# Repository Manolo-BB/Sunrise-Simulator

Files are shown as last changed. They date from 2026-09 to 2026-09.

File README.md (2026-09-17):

# Sunrise-Simulator
The aim of this project is to create a sunrise simulator to replace my mobile phone as an alarm clock. It works independently, without the need for an app. A second aim is to be cheaper than the alarm clocks currently available on the market, whilst still incorporating all the features I want.

## License

This project is licensed under the CC BY-NC-SA 4.0 License.

You may use, modify and distribute this project for non-commercial purposes.
Commercial use is not permitted.

See the [LICENSE](./LICENSE) file for details.

## Features

### General
- Run on main power and a backup battery
- Permanent time display + backlight when a button is pressed (The time is updated every minute via the RTC module. The local time is updated via Wi-Fi every 24 hours at 3:30am to take account of time changes)

### Alarm clock
- Set the alarm time
- Select the wake-up interval (default 30 mins)
- Choose an alarm tone (selection of 5 sounds)
- Alarm scheduling feature (weekdays/weekends)
- Ability to turn off the alarm before it ring
- Ability to set multiple alarms simultaneously

### lighting
- Switching on the light in bedside lamp mode
- Selecting easily the light 
- Selecting the brightness level

## Material
The idea is to reuse personal items rather than buying new ones; that is why some components may not be optimised. The whole project is designed to work with a 12V LED strip.

### Hardware

| Function | Component | Price |
| --- | --- | ---: |
| Microcontroller / Main Control | ESP32 DevKit V1 | €5.99 |
| Lighting | WS2812B LED Strip | Personal stock |
| Power Supply | 12 V – 1.5 A AC/DC Power Supply | Second-hand |
| Power Connector | DC Female PCB Connector | €0.32 |
| Voltage Regulation | MP1584EN Buck Converter | €1.15 |
| **Audio / Alarm** | MAX98357A Audio Amplifier | €1.72 |
| | 4 Ω – 3 W Speaker | Personal stock |
| | Micro SD / TF / SD Mini Card Reader – SPI, 3.3 V / 5 V | €2.07 |
| **Display** | 2.9" E-Ink / E-Paper Display – SPI https://github.com/WeActStudio/WeActStudio.EpaperModule/tree/master | €13.54 |
| **Backlight** | 2 White LEDs + Diffuser + R (100Ohm and 100kOhm) + transistor BS170 | Personal stock |
| **Navigation** | Bipolar Toggle Switch | €1.50 |
| | 4 Momentary Push Buttons | €8.53 |
| **RTC** | DS3231 Real-Time Clock Module | €6.79 |
| **Power Path Controller** | MCP73871 | €4.90 |
| | 18650 Battery | €12.90 |
| | Battery Adapter | €1.02 |
| | **Total** | **€62.42** |

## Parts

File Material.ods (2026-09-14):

Fonctionnalité | Matériel | Prix | Commandé | Reçu | Fournisseur
Cerveau/Microcontroleur | ESP32 | 5,99 |  |  | Aliexpress
Lumière | Bande led | 0 |  |  | Perso | Somme : | 62,42
Alimentation | Alim AC/DC 12V | 0
 | Connecteur DC Femelle pcb | 0,32 |  |  | Aliexpress
Réduire la tension pour alimenter le microcontroleur et l’ampli | MP1584EN | 1,15 |  |  | https://fr.aliexpress.com/item/1005010312349706.html?curPageLogUid=LkkoFZaAEUUE
Sonnerie audio | Amplificateur audio : MAX98357A | 1,72 |  |  | https://fr.aliexpress.com/item/1005010526780490.html?curPageLogUid=zXnH42P4dpTz
 | HP 4 Ohm 3W | 0 |  |  | Perso
 | Lecteur SD | 2,07 |  |  | https://fr.aliexpress.com/item/1005011847845537.html?curPageLogUid=lBjsuPfVD7UQ
Affichage | Ecran E-INK | 13,54 |  |  | https://fr.aliexpress.com/item/1005009572730414.html?curPageLogUid=gsFq02Ds4cs0
 | 2 Leds blanches diffuseur |  |  |  | Perso
Navigation | Switch ON-OFF lumière | 1,5 |  |  | IL2RTCI
 | 4 buttons | 8,53 |  |  | https://fr.aliexpress.com/item/1005007474109734.html?mp=1
RTC | DS3231 | 6,79 |  |  | https://fr.aliexpress.com/item/1005008634866851.html?src=bing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
Power path controller | MCP73871 | 4,9 |  |  | https://fr.aliexpress.com/item/1005011581134932.html?curPageLogUid=OKFyTIkfJm67
 | Batterie 18650 | 12,9 |  |  | BAT18650-3500/1
 | adaptateur batterie | 1,02 |  |  | Ali
 | DIP pour connecter ESP | 1,99 |  |  | Ali

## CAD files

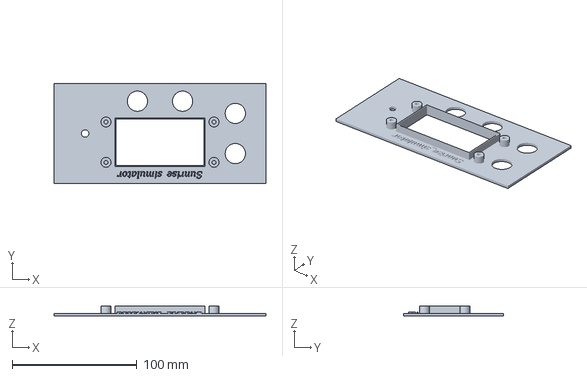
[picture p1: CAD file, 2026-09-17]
front_plate-Front plat.3mf
170.0 x 80.0 x 8.30 mm

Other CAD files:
front_plate.FCStd
front_plate-Front plat.stl

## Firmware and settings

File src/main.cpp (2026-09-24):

//Global libraries
#include <Arduino.h>
#include "config.h"

//Hardware functions
#include "hardware/lighting.h"
#include "hardware/button.h"
#include "hardware/screen.h"
#include "hardware/rtc.h"
#include "hardware/sd_card.h"
#include "hardware/audio.h"

//Modes functions
#include "modes/light_mode.h"
#include "modes/menu_mode.h"
#include "modes/clock.h"
#include "modes/alarm.h"

//Variables
static int lastDisplayedHour = -1;
static int lastDisplayedMinute = -1;
static int lastDisplayedDay = -1;
static int lastDisplayedMonth = -1;
static int lastDisplayedYear = -1;

static bool wasMenuActive = false;

//Function for configuring all hardware and modes run once at first power on
void setup()
{
    //Begin serial communication for debugging
    Serial.begin(115200);

    //Hardware initialisation
    rtc_init();
    buttons_init();
    sd_card_init(); //Be carefull and make the SD init before screen init to allow good initialization of both
    audio_init();
    screen_init();

    //Modes initialisation
    light_mode_init();
    menu_init();
    alarm_init();

    //Initial display
    screen_show_home_complete(rtc_get_hour(), rtc_get_minute(), alarm_is_enabled(0), alarm_is_enabled(1), alarm_is_enabled(2), alarm_is_enabled(3), alarm_is_enabled(4));

    Serial.println("================================");
    Serial.println("        Sunrise Simulator       ");
    Serial.println("================================");
}

//Main function that runs continuously
void loop()
{   
    //Reading the actions on the buttons
    buttons_update();
    backlight_update();
    audio_update();
    alarm_sunrise_update();
    
    //We only adjust the colour and brightness of the light when the menu is not active (the ‘+’ and ‘-’ buttons are used for other functions within the menu)
    if (!menu_is_active() && !alarm_sunrise_is_active())
    {
        light_mode_update();
    }
    
    //We increment the software clock and update the internal variables
    rtc_update();
    clock_update();
    menu_update();

    //We collect the information before it is displayed
    int hour = rtc_get_hour();
    int minute = rtc_get_minute();
    uint8_t day = rtc_get_day();
    uint8_t month = rtc_get_month();
    uint16_t year = rtc_get_year();

    //Depending on the values of the internal variables, we adjust the display
    //If the user exits the menu, we redraw everything
    if (wasMenuActive && !menu_is_active()){
        screen_show_home_complete(hour, minute, alarm_is_enabled(0), alarm_is_enabled(1), alarm_is_enabled(2), alarm_is_enabled(3), alarm_is_enabled(4));
        lastDisplayedHour = hour;
        lastDisplayedMinute = minute;
    }

    //If the time has changed, we only update the time
    if (!menu_is_active())
    {
        if (hour != lastDisplayedHour || minute != lastDisplayedMinute)
        {
            lastDisplayedHour = hour;
            lastDisplayedMinute = minute;
            screen_show_home(hour, minute);
        }
    }

    //If the date has changed, we only update the date
    if (day != lastDisplayedDay || month != lastDisplayedMonth || year != lastDisplayedYear)
    {
        screen_update_home_date();

        lastDisplayedDay = day;
        lastDisplayedMonth = month;
        lastDisplayedYear = year;
    }
    wasMenuActive=menu_is_active();
}

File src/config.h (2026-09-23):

#ifndef CONFIG_H
#define CONFIG_H

/*Basic ESP32 SPI configuration used for the diplay and SD module (see SPI.h configuration)
SCL(SCK)=18
SDA(MOSI)=23
*/

//Pins 2, 5, 12, 15  use for boot strap but works with this application
//Pins 34, 35 are input only

//Display pins
#define DISPLAY_CS          5  
#define DISPLAY_BUSY        22
#define DISPLAY_RES         19
#define DISPLAY_DC          21

//Light pin
#define LIGHT_PIN           17
#define BACKLIGHT_PIN       13

//Button pins
#define SWITCH_LIGHT_PIN    16
#define BUTTON_PLUS_PIN     15
#define BUTTON_MINUS_PIN    32
#define BUTTON_VALIDATE_PIN 4
#define BUTTON_PARAM_PIN    33

//RTC pins
#define RTC_SDA             27  
#define RTC_SCL             14

// Audio amplifier (MAX98357A)
#define AMP_EN              25
#define LRCLK               26
#define BCLK                12  
#define DIN                 1 // Do not use Serial in other functions when GPIO1 is used as I2S DIN

//SD pins, SCK and MOSI are shared with the display
#define SD_CS               2  
#define SD_MISO             35

#endif

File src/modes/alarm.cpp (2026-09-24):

#include <Arduino.h>
#include "alarm.h"

#include "../hardware/button.h"
#include "../hardware/screen.h"
#include "../hardware/audio.h"
#include "../hardware/rtc.h"
#include "../hardware/lighting.h"

struct Alarm
{
    uint8_t hour;
    uint8_t minute;
    uint8_t risingTime;
    uint8_t sound;
    bool monday;
    bool tuesday;
    bool wednesday;
    bool thursday;
    bool friday;
    bool saturday;
    bool sunday;
    bool enabled;
};

static Alarm alarms[NUMBER_OF_ALARMS] =
{
    {9,  0, 30, 1, true, true,  true,  true,  true,  false, false, false},
    {10,  0, 30, 2, true, true,  true,  true,  true,  false, false, false},
    {14,  0, 5, 3, true, true,  true,  true,  true,  false, false, false},
    {19,  00, 20, 4, true, true,  true,  true,  true,  false, false, true},
    {18,  55, 30, 5, true, true,  true,  true,  true,  false, false, true},
};

// Alarm selection state
static uint8_t selectedAlarm = 0;
static bool selectionFinished = false;

// Alarm setting state
static AlarmSettingStep settingStep = ALARM_SET_HOUR;
static bool settingFinished = false;

static uint8_t settingHour = 0;
static uint8_t settingMinute = 0;
static uint8_t settingRisingTime = 0;
static uint8_t settingSound = 1;
static bool settingMonday = false;
static bool settingTuesday = false;
static bool settingWednesday = false;
static bool settingThursday = false;
static bool settingFriday = false;
static bool settingSaturday = false;
static bool settingSunday = false;
static bool settingEnabled = false;

// Blink management
static unsigned long lastBlinkTime = 0;
static bool blinkOn = true;

// Setting days management
static uint8_t selectedDay = 0;

static unsigned long validatePressStartTime = 0;
static bool validateLongHandled = false;

// Sunrise simulation state
static uint8_t currentSunriseBrightness = 0;
static bool sunriseActive = false;

// Indicates whether an alarm occurrence has already been handled today
static bool alarmHandledToday[NUMBER_OF_ALARMS] = {false};
// Indicates whether an alarm is currently ringing
static bool alarmRinging[NUMBER_OF_ALARMS] = {false};
static uint8_t lastAlarmDay = 255;

static void alarm_start_hour_setting();
static void alarm_update_hour_setting();

static void alarm_start_minute_setting();
static void alarm_update_minute_setting();

static void alarm_start_rising_time_setting();
static void alarm_update_rising_time_setting();

static void alarm_start_sound_setting();
static void alarm_update_sound_setting();

static void alarm_start_days_setting();
static void alarm_update_days_setting();
static bool* alarm_get_selected_day_state();

static void alarm_start_enabled_setting();
static void alarm_update_enabled_setting();

static void alarm_save_settings();

static AlarmState alarm_get_state(uint8_t alarmIndex);

//Sunrise functions
static uint8_t alarm_get_sunrise_brightness(uint8_t alarmIndex);

static void alarm_check_new_day();
static void alarm_start_ringing(uint8_t alarmIndex);
static void alarm_validate(uint8_t alarmIndex);
static void alarm_update_validation();

static void alarm_start_hour_setting()
{
    blinkOn = true;
    lastBlinkTime = millis();

    button_clear_all();

    screen_show_alarm_time_setting_page( settingHour,settingMinute );
}

static void alarm_update_hour_setting()
{
    uint8_t plusCount = button_get_plus_count();
    uint8_t minusCount = button_get_minus_count();
    uint8_t validateCount = button_get_validate_count();

    bool valueChanged = (plusCount > 0 || minusCount > 0);

    // Blink hour
    unsigned long now = millis();

    if (now - lastBlinkTime >= BLINK_INTERVAL)
    {
        lastBlinkTime = now;
        blinkOn = !blinkOn;

        screen_update_alarm_setting_hour( settingHour, blinkOn);
    }

    // Increase hour
    while (plusCount--)
    {
        if (settingHour >= 23)
            settingHour = 0;
        else
            settingHour++;
    }

    // Decrease hour
    while (minusCount--)
    {
        if (settingHour == 0)
            settingHour = 23;
        else
            settingHour--;
    }

    if (valueChanged)
    {
        screen_update_alarm_setting_hour(settingHour, true);
    }

    // Validate hour
    if (validateCount > 0)
    {
        button_clear_all();

        settingStep = ALARM_SET_MINUTE;

        screen_update_alarm_setting_hour(settingHour,true);

        alarm_start_minute_setting();
    }
}

// Minutes settings
static void alarm_start_minute_setting()
{
    blinkOn = true;
    lastBlinkTime = millis();

    button_clear_plus_minus_count();
    button_clear_validate_count();

    screen_show_alarm_time_setting_page(settingHour, settingMinute);
}

static void alarm_update_minute_setting()
{
    uint8_t plusCount = button_get_plus_count();
    uint8_t minusCount = button_get_minus_count();
    uint8_t validateCount = button_get_validate_count();

    bool valueChanged = (plusCount > 0 || minusCount > 0);

    // Blink minute
    unsigned long now = millis();

    if (now - lastBlinkTime >= BLINK_INTERVAL)
    {
        lastBlinkTime = now;
        blinkOn = !blinkOn;

        screen_update_alarm_setting_minute( settingMinute, blinkOn);
    }

    // Increase minute
    while (plusCount--)
    {
        if (settingMinute >= 59)
            settingMinute = 0;
        else
            settingMinute++;
    }

    // Decrease minute
    while (minusCount--)
    {
        if (settingMinute == 0)
            settingMinute = 59;
        else
            settingMinute--;
    }

    if (valueChanged)
    {
        screen_update_alarm_setting_minute(settingMinute,true);
    }

    // Validate minute
    if (validateCount > 0)
    {
        button_clear_all();

        settingStep = ALARM_SET_RISING_TIME;

        screen_update_alarm_setting_minute(settingMinute, true);

        alarm_start_rising_time_setting();
    }
}

//Rising time settings
static void alarm_start_rising_time_setting()
{
    button_clear_plus_minus_count();
    button_clear_validate_count();

    screen_show_rising_time_setting_page( settingRisingTime);
}


static void alarm_update_rising_time_setting()
{
    uint8_t plusCount = button_get_plus_count();
    uint8_t minusCount = button_get_minus_count();
    uint8_t validateCount = button_get_validate_count();

    bool valueChanged = (plusCount > 0 || minusCount > 0);

    // Increase rising time
    while (plusCount--)
    {
        if (settingRisingTime < MAX_RISING_TIME)
            settingRisingTime++;
    }

    // Decrease rising time
    while (minusCount--)
    {
        if (settingRisingTime > MIN_RISING_TIME)
            settingRisingTime--;
    }

    if (valueChanged)
    {
        screen_update_rising_time_setting( settingRisingTime);
    }

    // Validate rising time
    if (validateCount > 0)
    {
        button_clear_all();

        screen_update_rising_time_setting( settingRisingTime);

        settingStep = ALARM_SET_SOUND;

        alarm_start_sound_setting();
    }
}
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

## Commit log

2026-09-08 organisation + lighting mode
    [Material.ods]
2026-09-14 datasheets and schematic
    [Material.ods, Sunrise_simulator.kicad_pcb, Sunrise_simulator.kicad_sch]
2026-09-15 ajout ecran
    [Sunrise_simulator.kicad_sch]
2026-09-17 ajout de la gestion RTC + rétroéclairage + front plate
    [Sunrise_simulator.kicad_sch, front_plate-Front plat.3mf, front_plate-Front plat.stl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]
2026-09-23 update kicad schematic
    [Sunrise_simulator.kicad_sch]
2026-09-23 ajout sonnerie + big refacto
    [Sunrise_simulator.kicad_sch]
2026-09-24 fix blinking hour in hour settings
    [main.cpp]
